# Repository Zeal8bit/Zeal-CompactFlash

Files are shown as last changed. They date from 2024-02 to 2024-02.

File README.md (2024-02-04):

## CompactFlash adapter for Zeal 8-bit Computer

<center>
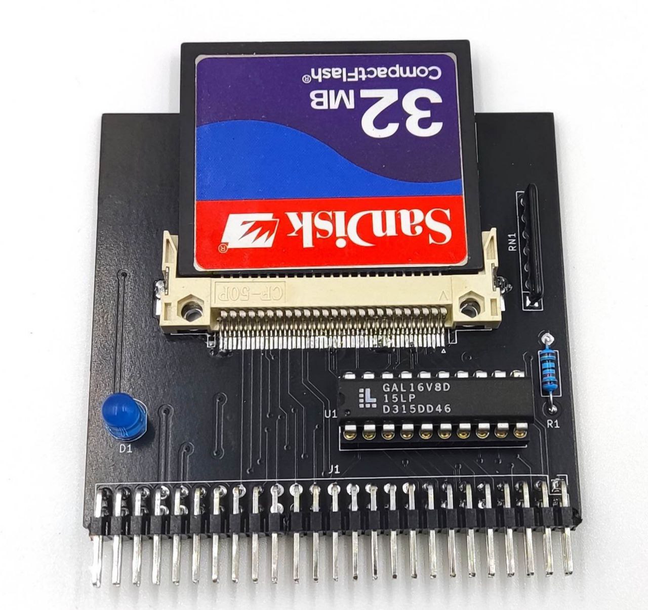
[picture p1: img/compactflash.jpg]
Preview
    
</center>

## This repository is part of [this Youtube video](https://youtu.be/B_ADYc3EVzc), check it for more information and explanation about this project.

The goal of this project is to create an adapter for connecting CompactFlash cards to Zeal 8-bit Computer.

This repository includes:

* An example/driver written in Z80 assembly to communicate with the adapter. It will read the first sector (512 bytes) of the card, show the first two 16-byte line, invert them and write the result back in the CompactFlash. Both 16-byte lines will be printed on screen.
* A Kicad project for the schematics and PCB board

The output of the example on Zeal 8-bit OS should look like this:

<center>
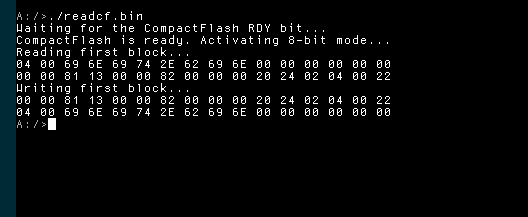
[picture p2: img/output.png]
Output
    
</center>

## About the connector

<s>As described in [the Youtube video](https://youtu.be/B_ADYc3EVzc), the CompactFlash connector needs to accept cards inserted bottom up. This is because the footprint of the connector is mirrored on the PCB.</s>

**Update v1.0.0:** the PCB and its connector have been fixed, the card can be connected upside up.

## Requirements

To compile this example you will need:
* bash
* git (to clone this repo)
* make
* Zeal 8-bit OS source code. Only the kernel_headers directory is required, check [this repository](https://github.com/Zeal8bit/Zeal-8-bit-OS).
* z88dk v2.2 (or later). Only its assembler, z80asm, is strictly required. The latest version of z80asm must be used as earlier versions don't have support for MACRO.

To install z88dk, please check out their Github project.

## Build

To build the program, define the path to Zeal 8-bit OS, this will let us find the header files used to assemble the example:

```
export ZOS_PATH=/your/path/to/Zeal8bitOS
```

Then simply use the command:

```
make
```

After compiling, the folder `bin/` should contain the binary `readcf.bin`. This file can be then loaded to Zeal 8-bit OS through UART thanks to the `load` command.

The binary can also be embedded within the romdisk that will contain both the OS and a read-only file system. For example:

```
cd $ZOS_PATH
export EXTRA_ROMDISK_FILES="/path/to/this/repo/bin/readcf.bin"
make
```
More info about compiling Zeal 8-bit OS [here](https://github.com/Zeal8bit/Zeal-8-bit-OS#getting-started).

The resulted ROM image can then be provided to an emulator or directly flashed to the computer's ROM that will use it.

## License

Distributed under the Creative Commons Zero v1.0 Universal License. See LICENSE file for more information.

You are free to use it for personal and commercial use, the boilerplate present in each file must not be removed.

## Contact

For any suggestion or request, you can contact me at contact [at] zeal8bit [dot] com or on the Discord server https://discord.gg/UzEjwRvBBb

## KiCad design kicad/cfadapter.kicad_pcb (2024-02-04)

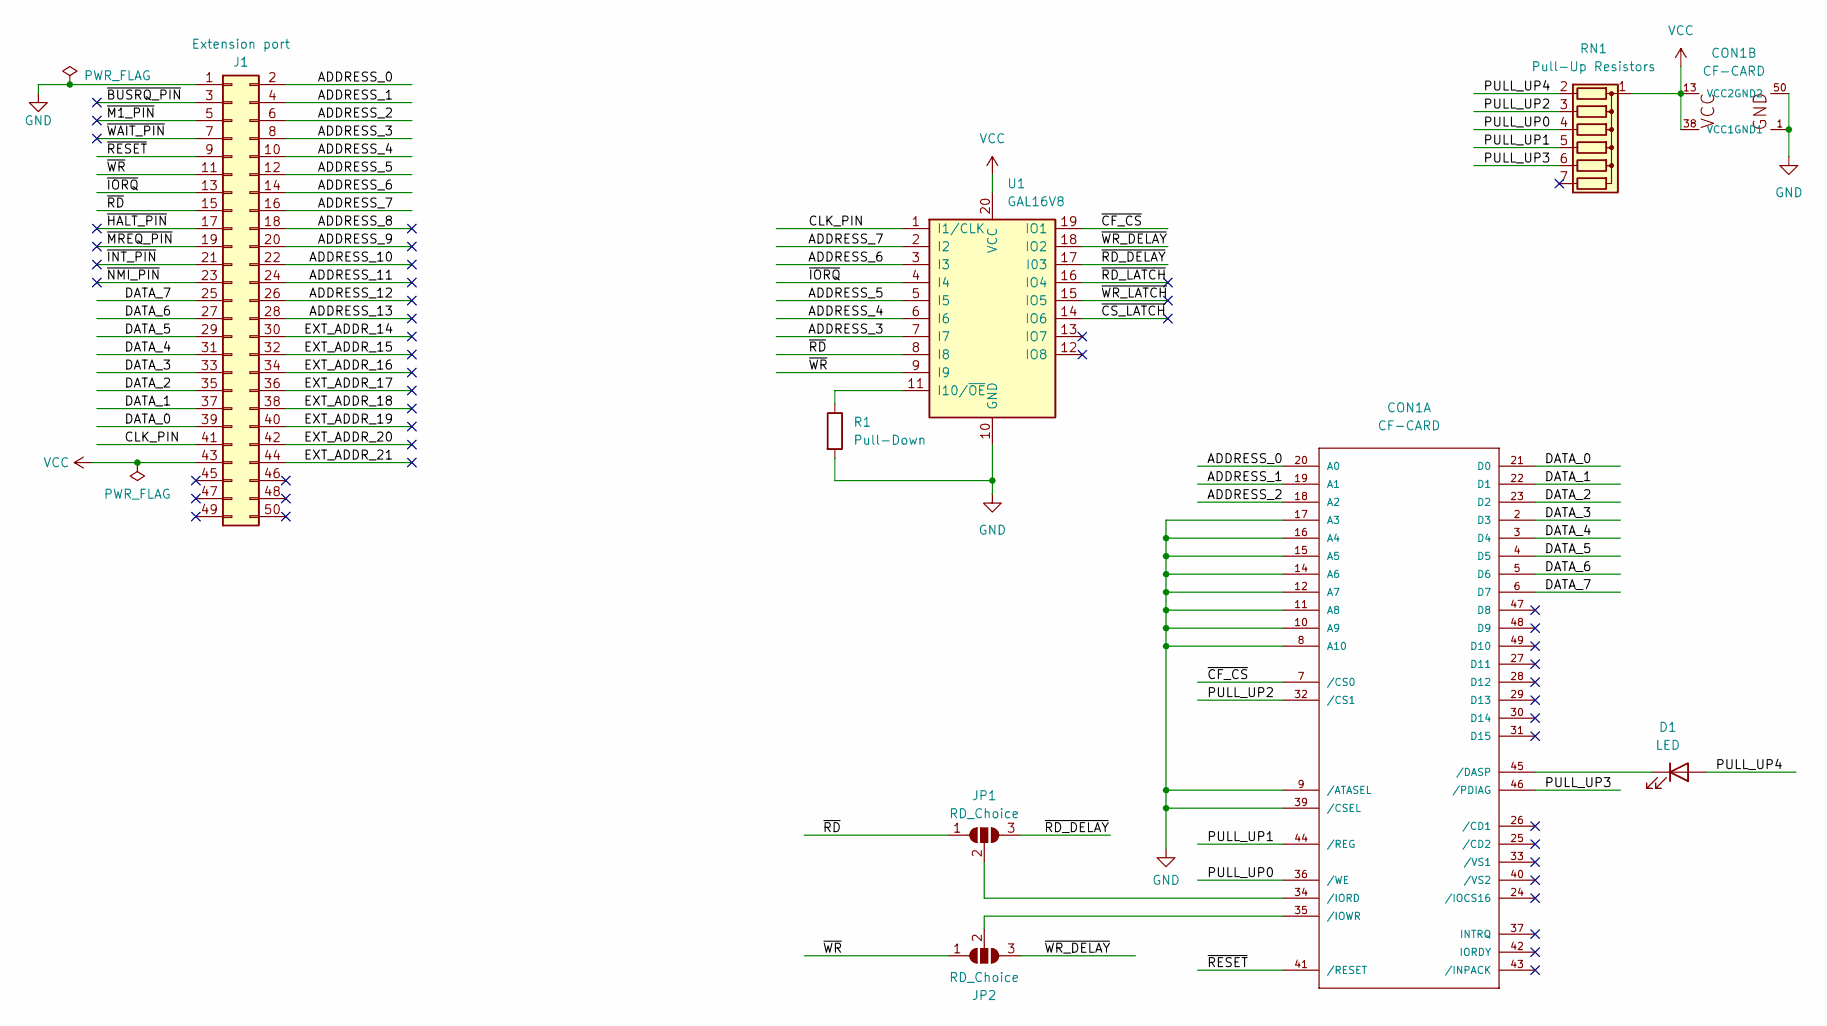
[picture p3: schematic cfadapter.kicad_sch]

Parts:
CON1: CF-CARD; CF-Card_3M_N7E50-E516xx-30
D1: LED; LED_D5.0mm
J1: Extension port; PinHeader_2x25_P2.54mm_Vertical
JP1, JP2: RD_Choice; SolderJumper-3_P2.0mm_Open_TrianglePad1.0x1.5mm_NumberLabels
R1: Pull-Down; R_Axial_DIN0207_L6.3mm_D2.5mm_P10.16mm_Horizontal
RN1: Pull-Up Resistors; R_Array_SIP7
U1: GAL16V8; DIP-20_W7.62mm_Socket

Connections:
/ADDRESS_0: CON1.20 (A0), J1.2
/ADDRESS_1: CON1.19 (A1), J1.4
/ADDRESS_2: CON1.18 (A2), J1.6
/ADDRESS_3: J1.8, U1.7 (I7)
/ADDRESS_4: J1.10, U1.6 (I6)
/ADDRESS_5: J1.12, U1.5 (I5)
/ADDRESS_6: J1.14, U1.3 (I3)
/ADDRESS_7: J1.16, U1.2 (I2)
/ADDRESS_8: J1.18
/ADDRESS_9: J1.20
/ADDRESS_10: J1.22
/ADDRESS_11: J1.24
/ADDRESS_12: J1.26
/ADDRESS_13: J1.28
/CLK_PIN: J1.41, U1.1 (I1/CLK)
/DATA_0: CON1.21 (D0), J1.39
/DATA_1: CON1.22 (D1), J1.37
/DATA_2: CON1.23 (D2), J1.35
/DATA_3: CON1.2 (D3), J1.33
/DATA_4: CON1.3 (D4), J1.31
/DATA_5: CON1.4 (D5), J1.29
/DATA_6: CON1.5 (D6), J1.27
/DATA_7: CON1.6 (D7), J1.25
/EXT_ADDR_14: J1.30
/EXT_ADDR_15: J1.32
/EXT_ADDR_16: J1.34
/EXT_ADDR_17: J1.36
/EXT_ADDR_18: J1.38
/EXT_ADDR_19: J1.40
/EXT_ADDR_20: J1.42
/EXT_ADDR_21: J1.44
/PULL_UP0: CON1.36 (/WE), RN1.4 (R3)
/PULL_UP1: CON1.44 (/REG), RN1.5 (R4)
/PULL_UP2: CON1.32 (/CS1), RN1.3 (R2)
/PULL_UP3: CON1.46 (/PDIAG), RN1.6 (R5)
/PULL_UP4: D1.2 (A), RN1.2 (R1)
/~BUSRQ_PIN: J1.3
/~CF_CS: CON1.7 (/CS0), U1.19 (IO1)
/~CS_LATCH: U1.14 (IO6)
/~HALT_PIN: J1.17
/~INT_PIN: J1.21
/~IORQ: J1.13, U1.4 (I4)
/~M1_PIN: J1.5
/~MREQ_PIN: J1.19
/~NMI_PIN: J1.23
/~RD_DELAY: JP1.3 (B), U1.17 (I03)
/~RD_LATCH: U1.16 (IO4)
/~RD: J1.15, JP1.1 (A), U1.8 (I8)
/~RESET: CON1.41 (/RESET), J1.9
/~WAIT_PIN: J1.7
/~WR_DELAY: JP2.3 (B), U1.18 (IO2)
/~WR_LATCH: U1.15 (IO5)
/~WR: J1.11, JP2.1 (A), U1.9 (I9)
GND: CON1.1 (GND1), CON1.8 (A10), CON1.9 (/ATASEL), CON1.10 (A9), CON1.11 (A8), CON1.12 (A7), CON1.14 (A6), CON1.15 (A5), CON1.16 (A4), CON1.17 (A3), CON1.39 (/CSEL), CON1.50 (GND2), J1.1, R1.2, U1.10 (GND)
unnamed: CON1.45 (/DASP), D1.1 (K)
unnamed: CON1.34 (/IORD), JP1.2 (C)
unnamed: CON1.35 (/IOWR), JP2.2 (C)
unnamed: R1.1, U1.11 (I10/~OE)
VCC: CON1.13 (VCC2), CON1.38 (VCC1), J1.43, RN1.1 (common), U1.20 (VCC)

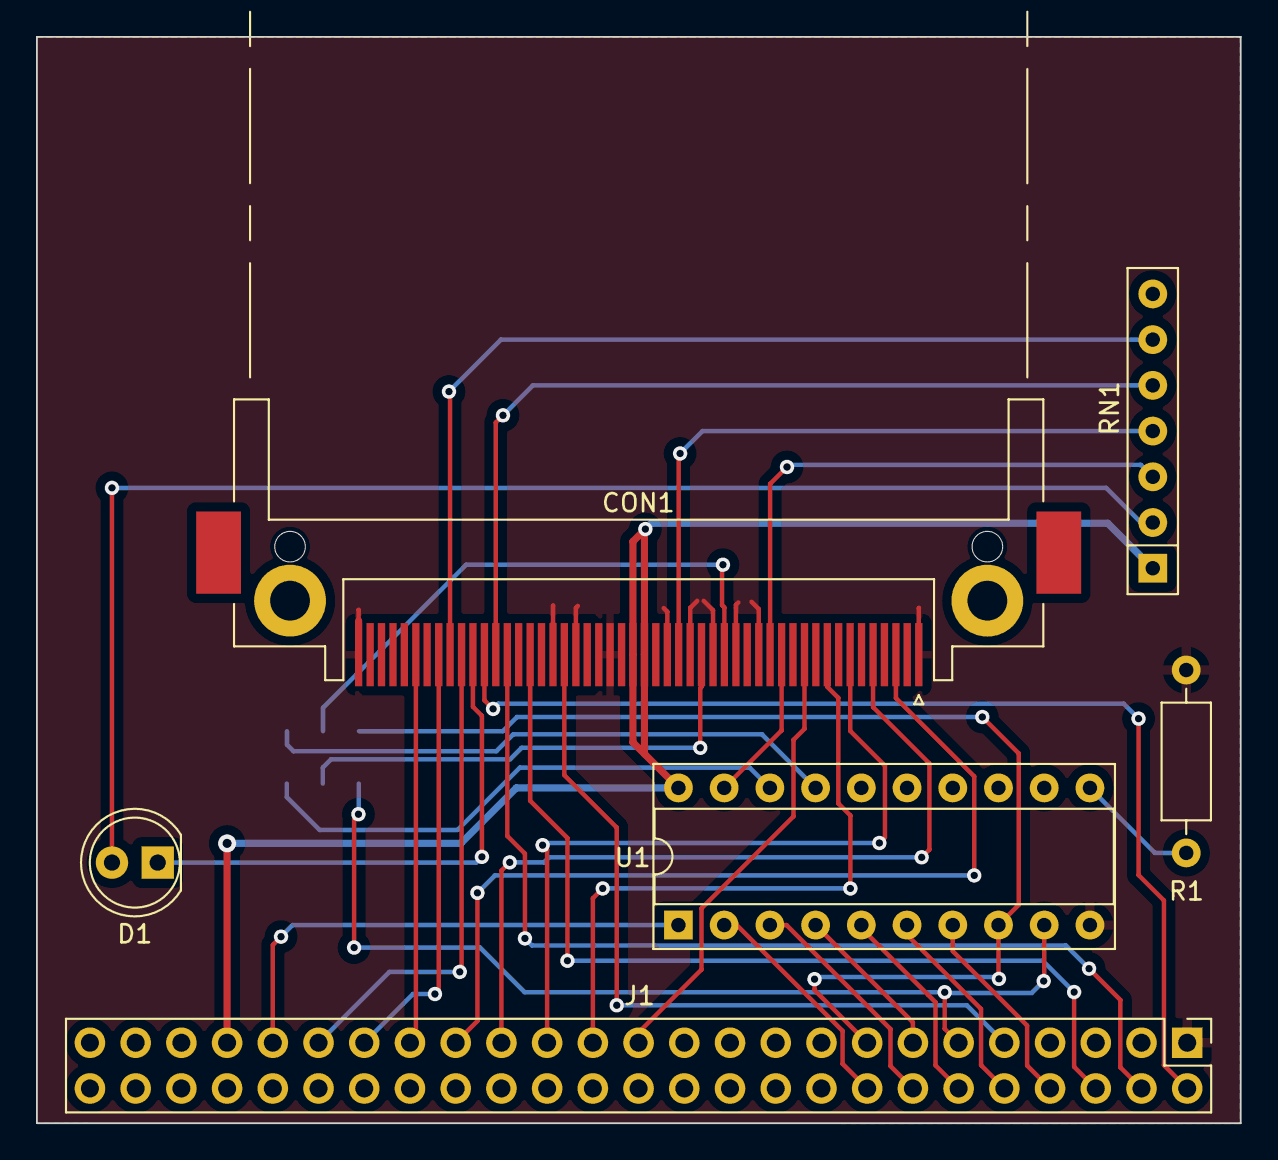
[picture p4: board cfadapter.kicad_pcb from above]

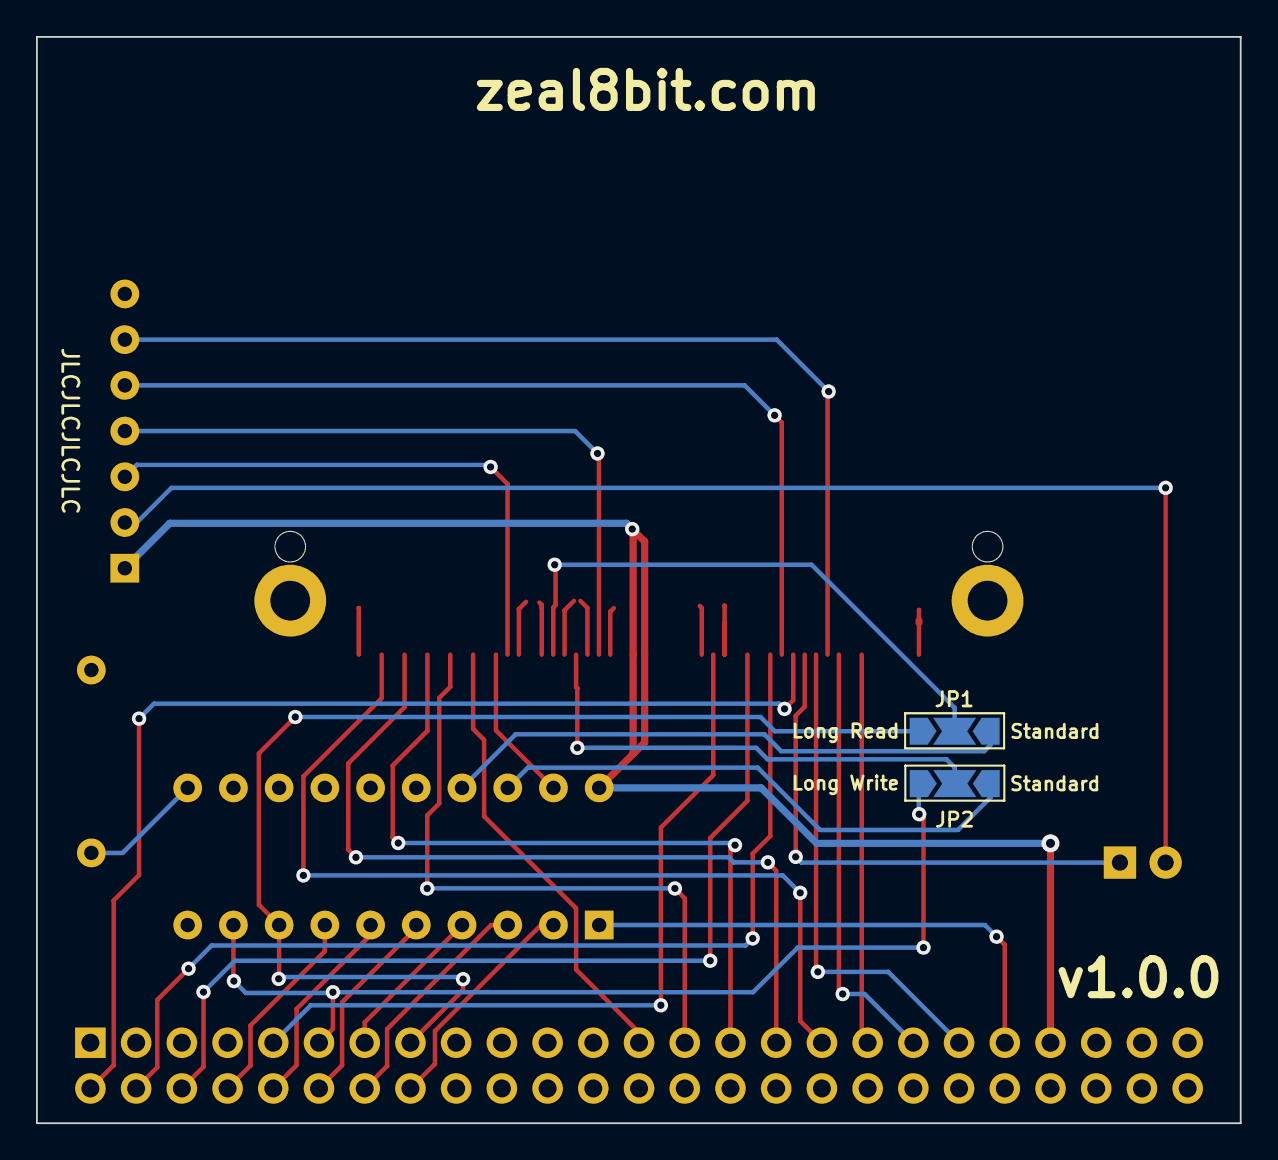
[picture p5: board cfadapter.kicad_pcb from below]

Board: 2 copper layers, 66.9 x 60.4 mm, 8 parts (2 on the bottom side), 35 nets.

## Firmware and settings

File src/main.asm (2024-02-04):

; SPDX-FileCopyrightText: 2023-2024 Zeal 8-bit Computer <contact@zeal8bit.com>
;
; SPDX-License-Identifier: CC0-1.0

    ; This example tests the read and write of the CompactFlash.
    ; It starts by reading the first 32 bytes of the CF, then, it inverts them
    ; and writes them back to the CompactFlash.
    ; Executing this program twice will restore the original content of the card.

    ; Include the Zeal 8-bit OS header file, containing all the syscalls macros.
    INCLUDE "zos_sys.asm"

    DEFC DEBUG_STATUS = 0

    ; Make the code start at 0x4000, as requested by the kernel
    ORG 0x4000

    DEFC CF_IO_ADDR     = 0x70
    DEFC CF_REG_DATA    = CF_IO_ADDR + 0
    ; Error and feature registers are the same
    DEFC CF_REG_ERROR   = CF_IO_ADDR + 1    ; RO
    DEFC CF_REG_FEATURE = CF_IO_ADDR + 1    ; WO
    DEFC CF_REG_SEC_CNT = CF_IO_ADDR + 2
    DEFC CF_REG_LBA_0   = CF_IO_ADDR + 3
    DEFC CF_REG_LBA_8   = CF_IO_ADDR + 4
    DEFC CF_REG_LBA_16  = CF_IO_ADDR + 5
    DEFC CF_REG_LBA_24  = CF_IO_ADDR + 6

    ; For the command register, define the ones we are interested in
    DEFC CF_REG_COMMAND = CF_IO_ADDR + 7    ; WO
    DEFC COMMAND_READ_SECTORS  = 0x20
    DEFC COMMAND_READ_BUFFER   = 0xE4
    DEFC COMMAND_WRITE_SECTORS = 0x30
    DEFC COMMAND_FLUSH_CACHE   = 0xE7
    DEFC COMMAND_WRITE_BUFFER  = 0xE8
    DEFC COMMAND_IDENTIFY_DRV  = 0xEC
    DEFC COMMAND_SET_FEATURES  = 0xEF

    ; For the status register, define the different bit
    DEFC CF_REG_STATUS  = CF_IO_ADDR + 7    ; RO
    DEFC STATUS_BUSY_BIT = 7
    DEFC STATUS_RDY_BIT  = 6
    DEFC STATUS_DWF_BIT  = 5
    DEFC STATUS_DSC_BIT  = 4
    DEFC STATUS_DRQ_BIT  = 3
    DEFC STATUS_CORR_BIT = 2
    DEFC STATUS_ERR_BIT  = 0

    ; For the feature register, the different possibilities
    DEFC FEATURE_ENABLE_8_BIT  = 0x1
    DEFC FEATURE_DISABLE_8_BIT = 0x81


_start:
    ; Wait for the ready bit
    S_WRITE3(DEV_STDOUT, _start_msg, _start_msg_end - _start_msg)
    call wait_for_ready
    S_WRITE3(DEV_STDOUT, _ready_msg, _ready_msg_end - _ready_msg)
    ; Write "Enable 8-bit mode" feature in feature register
    ld a, FEATURE_ENABLE_8_BIT
    out (CF_REG_FEATURE), a
    ; Issue a "Set feature" command
    ld a, COMMAND_SET_FEATURES
    out (CF_REG_COMMAND), a
    ; Wait for the CF to be ready again
    call wait_for_ready
    ; Make sure A is 0, else return an error
    or a
    jp nz, cf_error_occurred
    S_WRITE3(DEV_STDOUT, _read_msg, _read_msg_end - _read_msg)
    ; Read the first sector
    ld c, 0
    call read_sector
    ; 512 bytes have been read, print the first 32 bytes.
    ld c, 2
    call print_16_bytes_line
    ; Invert the first two lines of the buffer
    call invert_lines
    ; Write the buffer to the first sector of the compact flash
    ld c, 0
    call write_sector
    ; Read the sector again
    ld c, 0
    call read_sector
    ; Print the first two lines again
    ld c, 2
    call print_16_bytes_line
    ; We MUST execute EXIT() syscall at the end of any program.
    EXIT()


    ; Read a sector inside the RAM buffer _sector_buffer
    ; Parameters:
    ;   C - Sector number (0 - 255) to read
read_sector:
    ld a, c
    out (CF_REG_LBA_0), a
    ; Set the other LBA bits to 0
    xor a
    out (CF_REG_LBA_8), a
    out (CF_REG_LBA_16), a
    ; For LBA_24 register, we must set the upper 3 bits
    ld a, 0xE0
    out (CF_REG_LBA_24), a
    ; Number of sectors to read: 1
    ld a, 1
    out (CF_REG_SEC_CNT), a
    ; Issue a read sector command
    ld a, COMMAND_READ_SECTORS
    out (CF_REG_COMMAND), a
    ; Wait for the disk to be ready
    call wait_for_ready
    or a
    jp nz, cf_error_occurred
    ; We can start reading the data. We have to read 512 bytes, even though we don't
    ; need them all.
    ld c, CF_REG_DATA
    ld hl, _sector_buffer
    ; 256 bytes to read
    ld b, 0
    inir
    ; 256 bytes to read, again. All are already set.
    inir
    ret


    ; Write a sector with data from the RAM buffer _sector_buffer
    ; Parameters:
    ;   C - Sector number (0 - 255) to write
write_sector:
    push bc
    S_WRITE3(DEV_STDOUT, _write_msg, _write_msg_end - _write_msg)
    pop bc
    ld a, c
    out (CF_REG_LBA_0), a
    xor a
    out (CF_REG_LBA_8), a
    out (CF_REG_LBA_16), a
    ld a, 0xE0
    out (CF_REG_LBA_24), a
    ld a, 1
    out (CF_REG_SEC_CNT), a
    ; Issue a WRITE sector command
    ld a, COMMAND_WRITE_SECTORS
    out (CF_REG_COMMAND), a
    ; Wait for the disk to be ready
    call wait_for_ready
    or a
    jp nz, cf_error_occurred
    ; We can fill the CompactFlash sector buffer
    ld c, CF_REG_DATA
    ld hl, _sector_buffer
    ld b, 0
    otir    ; output 256 bytes
    otir    ; output 256 bytes
    call wait_for_ready
    or a
    jp nz, cf_error_occurred
    ret


    ; Invert the first two lines
invert_lines:
    ld b, 16
    ld hl, _sector_buffer
    ld de, _sector_buffer + 16
_invert_lines_loop:
    ld c, (hl)
    ld a, (de)
    ld (hl), a
    ld a, c
    ld (de), a
    inc de
    inc hl
    djnz _invert_lines_loop
    ret


    ; Parameters:
    ;   C - Number of 16-byte lines to print
print_16_bytes_line:
    ld de, _sector_buffer
    push de
_read_big_loop:
    ld hl, _buffer
    ld b, 16
    ; Store each byte in a buffer, in ASCII format
_read_loop:
    ; Get the original buffer
    pop de
    ld a, (de)
    inc de
    push de
    call byte_to_ascii
    ld (hl), d
    inc hl
    ld (hl), e
    inc hl
    ld (hl), ' '
    inc hl
    djnz _read_loop
    ; Replace the last space by a new line
    dec hl
    ld (hl), '\n'
    ; The buffer should contain 48 characters, print it
    push bc
    S_WRITE3(DEV_STDOUT, _buffer, 48)
    pop bc
    dec c
    jr nz, _read_big_loop
    pop de
    ret

    ; Routine that waits for the CompactFlash to to be ready and not busy.
    ; Once its ready, return check for errors:
    ; Return 0 in A on success, 1 on error
wait_for_ready:
    in a, (CF_REG_STATUS)
  IF DEBUG_STATUS
    call print_a
  ENDIF
    ; Check that RDY bit is set and that BUSY bit is not set
    bit STATUS_RDY_BIT, a
    jr z, wait_for_ready
    bit STATUS_BUSY_BIT, a
    jr nz, wait_for_ready
    ; Device is ready, return the error bit in A
    and 1 << STATUS_ERR_BIT
    ret

  IF DEBUG_STATUS
print_a:
    push af
    call byte_to_ascii
    ld hl, buf
    ld (hl), d
    inc hl
    ld (hl), e
    dec hl
    ex de, hl
    ld bc, 3
    S_WRITE1(DEV_STDOUT)
    pop af
    ret
buf: defm "00\n"
  ENDIF


    ; An error occurred during a command, print a message
cf_error_occurred:
    ; Get the error register
    in a, (CF_REG_ERROR)
    ; Convert this value to ASCII (hex)
    call byte_to_ascii
    ld hl, _error_code
    ld (hl), d
    inc hl
    ld (hl), e
    ; Write it to the error message and print it
    S_WRITE3(DEV_STDOUT, _error_msg, _error_msg_end - _error_msg)
    ; Exit the program now
    EXIT()

_start_msg: DEFM "Waiting for the CompactFlash RDY bit...\n"
_start_msg_end:
_ready_msg: DEFM "CompactFlash is ready. Activating 8-bit mode...\n"
_ready_msg_end:
_read_msg:  DEFM "Reading first block...\n"
_read_msg_end:
_write_msg:  DEFM "Writing first block...\n"
_write_msg_end:
_error_msg: DEFM "Error 0x"
_error_code:
            DEFS 2
            DEFM"\n"
_error_msg_end:

_buffer: DEFS 64


    ; Convert an 8-bit value to ASCII (hex)
    ; Parameters:
    ;       A - Value to convert
    ; Returns:
    ;       D - First character
    ;       E - Second character
    ; Alters:
    ;       A
    PUBLIC byte_to_ascii
byte_to_ascii:
    ld e, a
    rlca
    rlca
    rlca
    rlca
    and 0xf
    call _byte_to_ascii_nibble
    ld d, a
    ld a, e
    and 0xf
    call _byte_to_ascii_nibble
    ld e, a
    ret
_byte_to_ascii_nibble:
    ; If the byte is between 0 and 9 included, add '0'
    sub 10
    jp nc, _byte_to_ascii_af
    ; Byte is between 0 and 9
    add '0' + 10
    ret
_byte_to_ascii_af:
    ; Byte is between A and F
    add 'A'
    ret

    ; Must be the last label of the example (to point to free RAM)
_sector_buffer:

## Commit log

2023-05-28 Publish program source code to read CompactFlash first sector on Zeal 8-bit Computer, as well as schematics and PCB designed in Kicad v6
    [cfadapter.kicad_pcb, cfadapter.kicad_sch]
2024-02-04 src/main.asm: Fix the example to properly read and write the CompactFlash
    [main.asm]
2024-02-04 kicad: Update the PCB to the manufactured v1.0.0
    [cfadapter.kicad_pcb, cfadapter.kicad_sch]
